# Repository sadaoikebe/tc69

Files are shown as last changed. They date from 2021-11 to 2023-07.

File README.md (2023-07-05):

# TC69 静電容量親指シフト 65% キーボード

## 特徴

オープンソースの親指シフトキーボードです。

* 静電容量式
* QMK対応
* JLCPCBで作成したPCB
* 3Dプリントしたケース

## キーボード配列

* ANSI配列ベース
* 矢印キーあり
* 対応する親指シフトファームウェア [tc69 firmware](https://github.com/sadaoikebe/qmk_firmware/tree/capacitive)
* 親指シフト対応、親指キーB下割れ
* 親指キーに3u/2.75uのキーキャップを使用

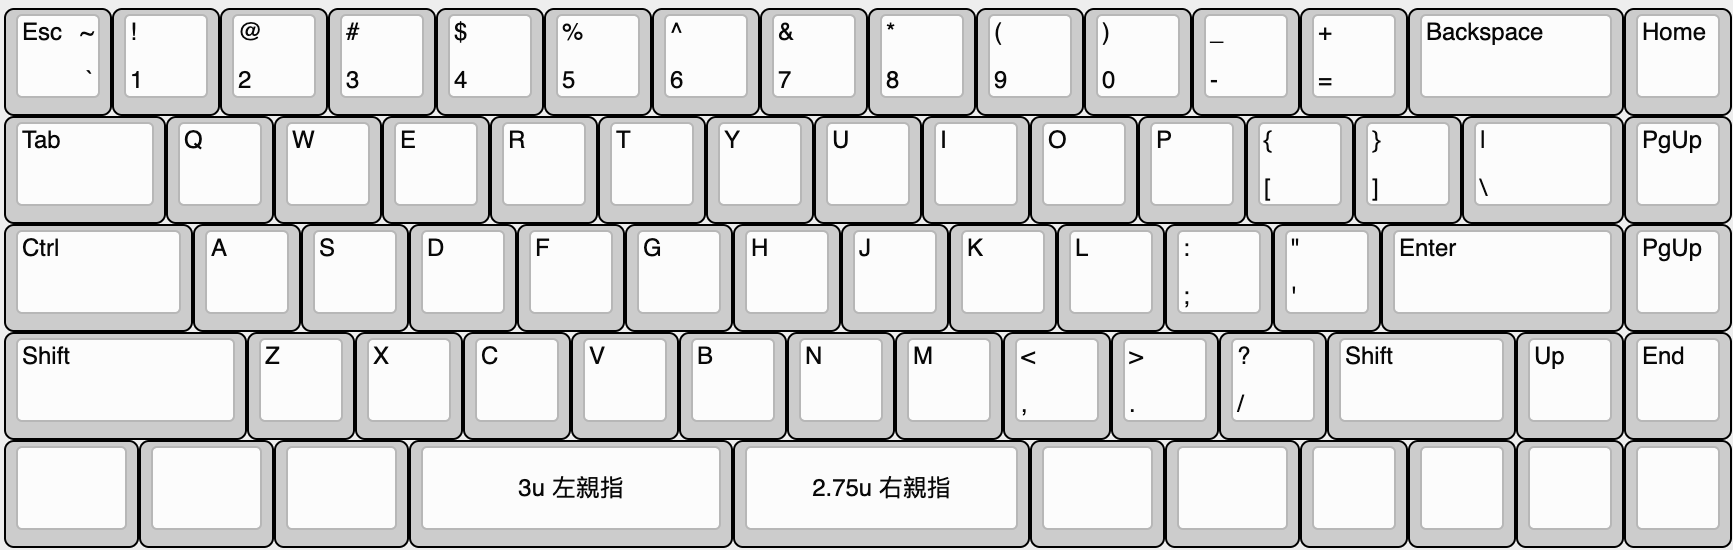
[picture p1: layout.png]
LAYOUT

<!--
["Esc\n\n~\n`","!\n1","@\n2","#\n3","$\n4","%\n5","^\n6","&\n7","*\n8","(\n9",")\n0","_\n-","+\n=",{w:2},"Backspace","Home"],
[{w:1.5},"Tab","Q","W","E","R","T","Y","U","I","O","P","{\n[","}\n]",{w:1.5},"|\n\\","PgUp"],
[{w:1.75},"Ctrl","A","S","D","F","G","H","J","K","L",":\n;","\"\n'",{w:2.25},"Enter","PgUp"],
[{w:2.25},"Shift","Z","X","C","V","B","N","M","<\n,",">\n.","?\n/",{w:1.75},"Shift","Up","End"],
[{a:7,w:1.25},"",{w:1.25},"",{w:1.25},"",{w:3},"3u 左親指",{w:2.75},"2.75u 右親指",{w:1.25},"",{w:1.25},"","","","",""],
-->

静電容量キーボードなので配列は固定で変えられません

# BOM

Item |ソース | 数量 |  備考
:--- | :--- | :--- | :---
TC69 PCBA | [JLCPCB PCBA](pcb/) | 1 |
オペアンプ AD8601ARTZ | AliEx/淘宝等 | 1 |
ロジック 74AHC1G04 | AliEx/淘宝等 | 1 |
ケース | [3D Printed](case/) | 1 | 
定位板 | [Laser Cut Brass](plate/) | 1 | t=1.5mm アクリルでも良いが割れやすい
ヒートセット M3x6mmx4.6mm | [AliEx/淘宝等](https://www.aliexpress.com/item/1005002288716120.html) | 8 | 長さは6mmでなくても良い
M3 円頭六角ボルト 6mm | | 8 |  
M2 低頭精密小ねじ M2*8mm FX-0280EB | [Wilco](https://wilco.jp/products/F/FX-EB.html#page3) | 12 |
クッション 2mm厚 x 60mm x 4mm | | 16 | Poron/EVAフォーム等
Seeed Xiao RP2040 | [Seeed Studio](https://www.seeedstudio.com/XIAO-RP2040-v1-0-p-5026.html) | 1 | 
NiZ プランジャーキット | [NiZ](https://www.nizkeyboard.com/products/2019-new-niz-ec-switch) | 1セット |
コニカルスプリング | [淘宝](https://item.taobao.com/item.htm?spm=a1z0d.6639537/tb.1997196601.4.194d74840XCdqh&id=616137021034) | 69 |
シリコンドーム | [NiZ](https://www.nizkeyboard.com/products/ec-silicone-domes-35g-45g-55g) | 1セット |
2u スタビライザー | AliEx/淘宝/自キ専門店等 | 5 | Plate Mount
3u スタビライザー | AliEx/淘宝/自キ専門店等 | 1 | Plate Mount
キーキャップ | AliEx/淘宝/自キ専門店等 | 1セット | 3u/2.75uの親指キーが必要

## 組み立て工程

1. 定位板はあらかじめM2タップを切る
2. PCBにXiao RP2040, オペアンプ, ロジックIC を取り付け
3. コニカルスプリングを並べてラバードームを乗せる
4. 定位板にハウジングを取り付け、プランジャーを通す
5. 定位板とPCBをM2*8ボルトで緊結する
6. PCBにクッションを貼る
7. ファームウェア書き込み
8. ケースに入れて完成

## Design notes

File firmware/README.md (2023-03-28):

# TC69 Firmware

Use QMK: [tc69 firmware](https://github.com/sadaoikebe/qmk_firmware/tree/capacitive)

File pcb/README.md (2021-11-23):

https://www.seeedstudio.com/blog/2020/04/23/use-seeeduino-xiao-in-kicad-pcb-design-like-a-components/

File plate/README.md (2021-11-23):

https://www.tinkercad.com/things/e4goL4K2fU2-tc69-plate

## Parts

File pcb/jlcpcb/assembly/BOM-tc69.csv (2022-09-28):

Comment | Designator | Footprint | LCSC
100k | R10,R11,R12,R13,R14,R15,R16,R17,R18,R19,R4,R5,R6,R7,R8,R9 | R_0805_2012Metric_Pad1.20x1.40mm_HandSolder | C149504
330p | C2 | C_0603_1608Metric_Pad1.08x0.95mm_HandSolder | C1664
100 | R3 | R_0805_2012Metric_Pad1.20x1.40mm_HandSolder | C17408
1k | R1 | R_0805_2012Metric_Pad1.20x1.40mm_HandSolder | C17513
43k | R2 | R_0805_2012Metric_Pad1.20x1.40mm_HandSolder | C17695
4051 | U4,U5 | SOIC-16_3.9x9.9mm_P1.27mm | C21379
100n | C1,C4,C5,C6 | C_0805_2012Metric_Pad1.18x1.45mm_HandSolder | C28233
74AHC1G04 | U2 | SOT-23-5_HandSoldering | C7465
AD8601ARTZ | U3 | SOT-23-5_HandSoldering | C89851
SeeeduinoXIAO | U1 | Seeeduino XIAO-MOUDLE14P-2.54-21X17.8MM
Y | SW32 | ecs_pad
LSHFT | SW4 | ecs_pad
0 | SW51 | ecs_pad
5 | SW26 | ecs_pad
TAB | SW2 | ecs_pad
6 | SW31 | ecs_pad
9 | SW46 | ecs_pad
2 | SW11 | ecs_pad
7 | SW36 | ecs_pad
ESC | SW1 | ecs_pad
CAPS | SW3 | ecs_pad
LCTRL | SW5 | ecs_pad
1 | SW6 | ecs_pad
Q | SW7 | ecs_pad
LWIN | SW10 | ecs_pad
W | SW12 | ecs_pad
S | SW13 | ecs_pad
Z | SW14 | ecs_pad
3 | SW16 | ecs_pad
E | SW17 | ecs_pad
D | SW18 | ecs_pad
X | SW19 | ecs_pad
LALT | SW20 | ecs_pad
4 | SW21 | ecs_pad
R | SW22 | ecs_pad
F | SW23 | ecs_pad
C | SW24 | ecs_pad
T | SW27 | ecs_pad
G | SW28 | ecs_pad
V | SW29 | ecs_pad
LSPC | SW30 | ecs_pad
H | SW33 | ecs_pad
B | SW34 | ecs_pad
U | SW37 | ecs_pad
J | SW38 | ecs_pad
N | SW39 | ecs_pad
8 | SW41 | ecs_pad
I | SW42 | ecs_pad
K | SW43 | ecs_pad
M | SW44 | ecs_pad
RSPC | SW45 | ecs_pad
O | SW47 | ecs_pad
L | SW48 | ecs_pad
COMMA | SW49 | ecs_pad
P | SW52 | ecs_pad
SCLN | SW53 | ecs_pad
DOT | SW54 | ecs_pad
RALT | SW55 | ecs_pad
MINUS | SW56 | ecs_pad
LBRC | SW57 | ecs_pad
QUOTE | SW58 | ecs_pad
SLSH | SW59 | ecs_pad
RWIN | SW60 | ecs_pad
EQUAL | SW61 | ecs_pad
RBRC | SW62 | ecs_pad
APP | SW65 | ecs_pad
BS | SW66 | ecs_pad
ENTER | SW68 | ecs_pad
RSHFT | SW69 | ecs_pad
LEFT | SW70 | ecs_pad
BSLSH | SW72 | ecs_pad
UP | SW74 | ecs_pad
DOWN | SW75 | ecs_pad
HOME | SW76 | ecs_pad
PGUP | SW77 | ecs_pad
PGDN | SW78 | ecs_pad
END | SW79 | ecs_pad
RIGHT | SW80 | ecs_pad
A | SW8 | ecs_pad

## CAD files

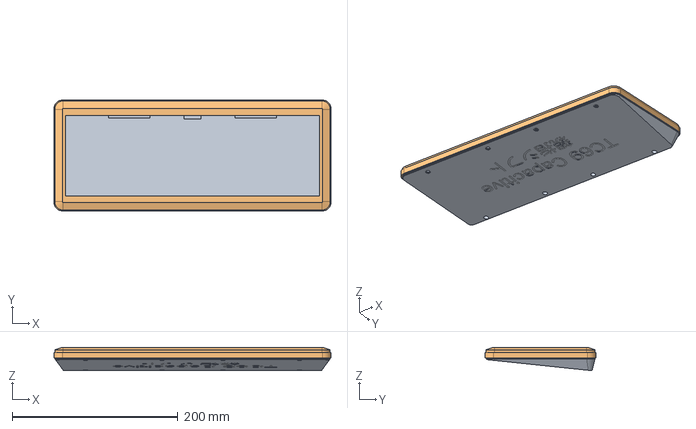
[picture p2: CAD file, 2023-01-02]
case/tc69-case.FCStd
334.0 x 133.5 x 28.2 mm
Base
Lid

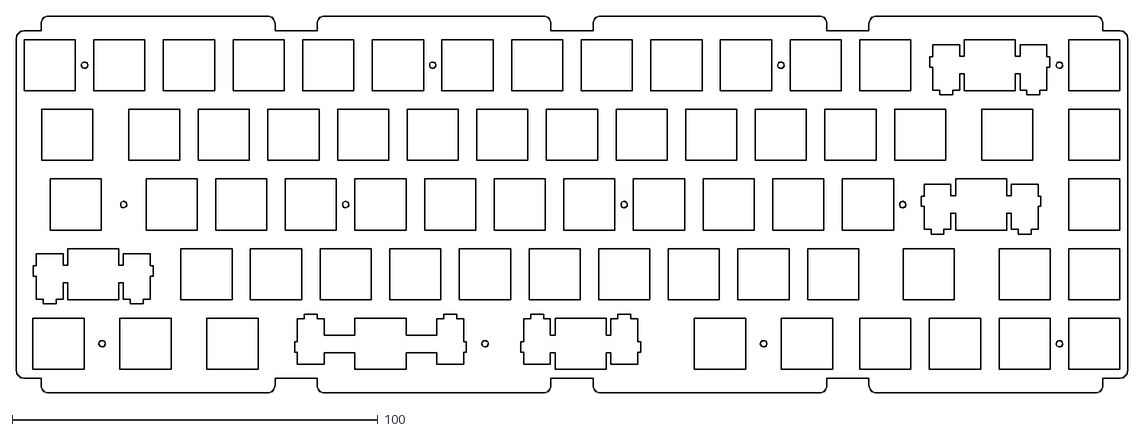
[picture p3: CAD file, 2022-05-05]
plate/tc69_plate.dxf
304.0 x 103.0

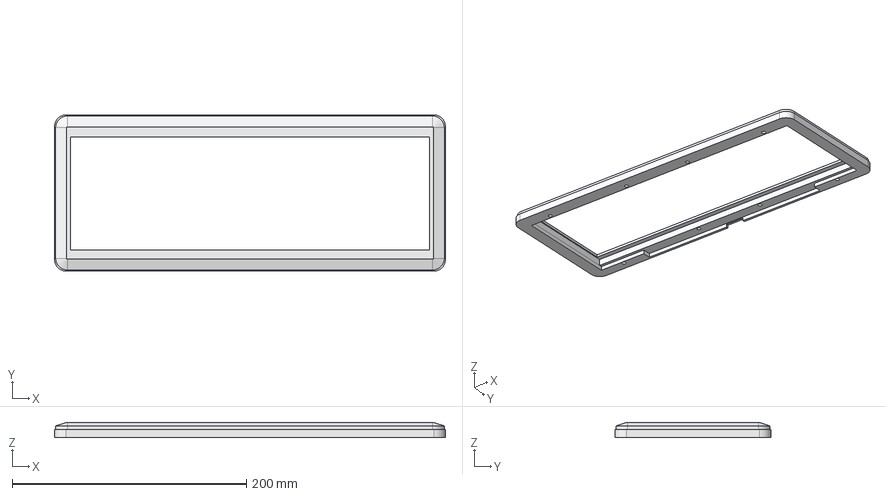
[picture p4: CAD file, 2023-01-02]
case/tc69-case-Lid.step
334.0 x 133.5 x 13.0 mm

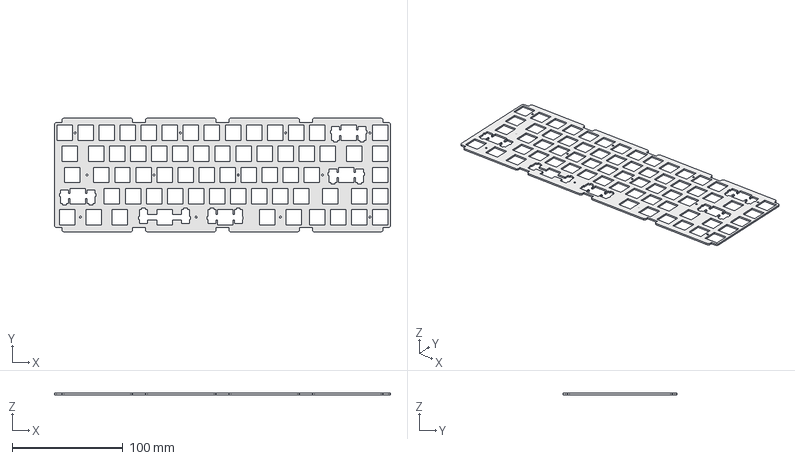
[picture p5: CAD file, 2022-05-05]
plate/plate.FCStd
304.0 x 103.0 x 1.50 mm

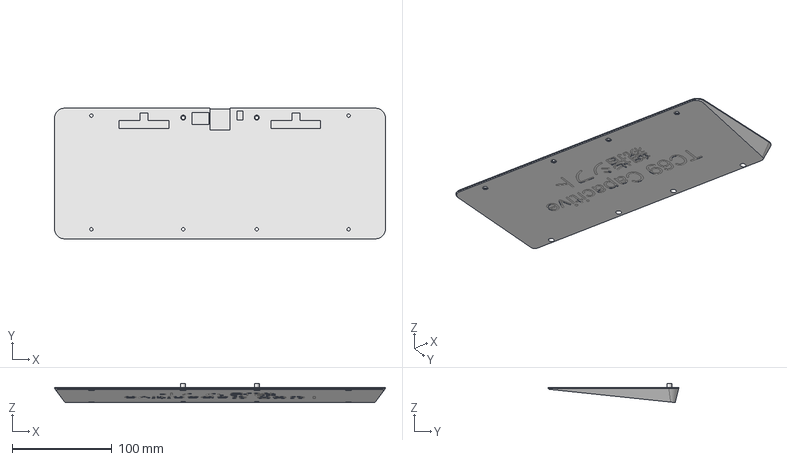
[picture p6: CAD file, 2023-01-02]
case/tc69-case-Base.step
332.0 x 131.0 x 19.2 mm

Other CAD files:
pcb/CapacitivePad.FCStd
case/tc69-case-Base.3mf
case/tc69-case-Lid.3mf

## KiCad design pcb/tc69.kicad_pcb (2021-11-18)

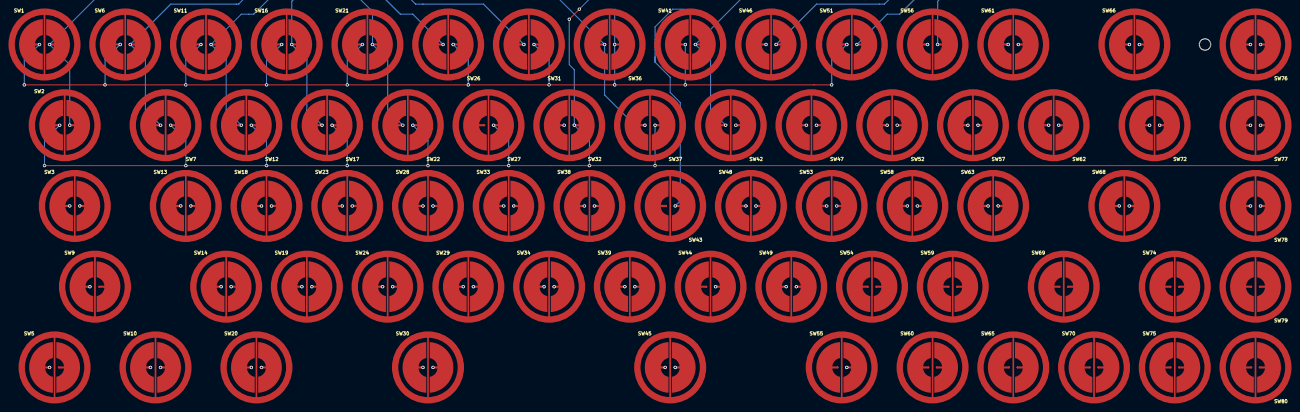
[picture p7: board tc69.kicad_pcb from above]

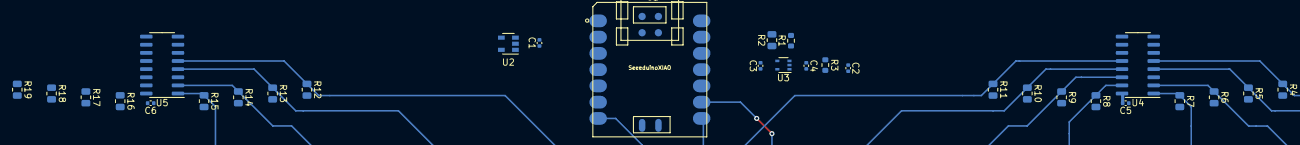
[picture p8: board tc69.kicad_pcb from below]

Board: 2 copper layers, 99 parts (30 on the bottom side), 32 nets.

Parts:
C1, C4, C5, C6: 100n; C_0402_1005Metric
C2: 330p; C_0402_1005Metric
C3: 10p; C_0402_1005Metric
R1: 1k; R_0603_1608Metric
R2: 43k; R_0805_2012Metric
R3: 100; R_0603_1608Metric
R4, R5, R6, R7, R8, R9, R10, R11, R12, R13, R14, R15, R16, R17, R18, R19: 100k; R_0805_2012Metric
SW1: ESC; ecs_pad
SW2: TAB; ecs_pad
SW3: CAPS; ecs_pad
SW5: LCTRL; ecs_pad
SW6: 1; ecs_pad
SW7: Q; ecs_pad
SW9: LSHFT; ecs_pad
SW10: LWIN; ecs_pad
SW11: 2; ecs_pad
SW12: W; ecs_pad
SW13: A; ecs_pad
SW14: Z; ecs_pad
SW16: 3; ecs_pad
SW17: E; ecs_pad
SW18: S; ecs_pad
SW19: X; ecs_pad
SW20: LALT; ecs_pad
SW21: 4; ecs_pad
SW22: R; ecs_pad
SW23: D; ecs_pad
SW24: C; ecs_pad
SW26: 5; ecs_pad
SW27: T; ecs_pad
SW28: F; ecs_pad
SW29: V; ecs_pad
SW30: LSPC; ecs_pad
SW31: 6; ecs_pad
SW32: Y; ecs_pad
SW33: G; ecs_pad
SW34: B; ecs_pad
SW36: 7; ecs_pad
SW37: U; ecs_pad
SW38: H; ecs_pad
SW39: N; ecs_pad
SW41: 8; ecs_pad
SW42: I; ecs_pad
SW43: J; ecs_pad
SW44: M; ecs_pad
SW45: RSPC; ecs_pad
SW46: 9; ecs_pad
SW47: O; ecs_pad
SW48: K; ecs_pad
SW49: COMMA; ecs_pad
SW51: 0; ecs_pad
SW52: P; ecs_pad
SW53: L; ecs_pad
SW54: DOT; ecs_pad
SW55: RALT; ecs_pad
SW56: MINUS; ecs_pad
SW57: LBRC; ecs_pad
SW58: SCLN; ecs_pad
SW59: SLSH; ecs_pad
SW60: RWIN; ecs_pad
SW61: EQUAL; ecs_pad
SW62: RBRC; ecs_pad
SW63: QUOTE; ecs_pad
SW65: APP; ecs_pad
SW66: BS; ecs_pad
SW68: ENTER; ecs_pad
SW69: RSHFT; ecs_pad
SW70: LEFT; ecs_pad
SW72: BSLSH; ecs_pad
SW74: UP; ecs_pad
SW75: DOWN; ecs_pad
SW76: HOME; ecs_pad
SW77: PGUP; ecs_pad
SW78: PGDN; ecs_pad
SW79: END; ecs_pad
SW80: RIGHT; ecs_pad
U1: SeeeduinoXIAO; Seeeduino XIAO-MOUDLE14P-2.54-21X17.8MM
U2: 74AHC1G04; SOT-23-5
U3: TLV9051; SOT-353_SC-70-5
U4, U5: 4051; SOIC-16_3.9x9.9mm_P1.27mm

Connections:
+5V: C1.2, C4.2, C5.2, C6.2, U1.14, U2.5, U3.5, U4.16, U5.16
ADC: C3.1, R2.1, U1.11, U3.4
GND: C1.1, C2.2, C4.1, C5.1, C6.1, R1.2, R4.2, R5.2, R6.2, R7.2, R8.2, R9.2, R10.2, R11.2, R12.2, R13.2, R14.2, R15.2, R16.2, R17.2, R18.2, R19.2, SW1.3, SW2.3, SW3.3, SW5.3, SW6.3, SW7.3, SW9.3, SW10.3, SW11.3, SW12.3, SW13.3, SW14.3, SW16.3, SW17.3, SW18.3, SW19.3, SW20.3, SW21.3, SW22.3, SW23.3, SW24.3, SW26.3, SW27.3, SW28.3, SW29.3, SW30.3, SW31.3, SW32.3, SW33.3, SW34.3, SW36.3, SW37.3, SW38.3, SW39.3, SW41.3, SW42.3, SW43.3, SW44.3, SW45.3, SW46.3, SW47.3, SW48.3, SW49.3, SW51.3, SW52.3, SW53.3, SW54.3, SW55.3, SW56.3, SW57.3, SW58.3, SW59.3, SW60.3, SW61.3, SW62.3, SW63.3, SW65.3, SW66.3, SW68.3, SW69.3, SW70.3, SW72.3, SW74.3, SW75.3, SW76.3, SW77.3, SW78.3, SW79.3, SW80.3, U1.13, U2.3, U3.2, U4.7, U4.8, U5.7, U5.8
IS0: U2.4, U5.6
unnamed: C3.2, R1.1, R2.2, U3.3
unnamed: R3.1, U3.1
S0: U1.1, U2.2, U4.6
S1: U1.2, U4.11, U5.11
S2: U1.3, U4.10, U5.10
S3: U1.4, U4.9, U5.9
SENSE: C2.1, R3.2, U1.10, U4.3, U5.3
col1: R4.1, SW1.2, SW2.2, SW3.2, SW5.2, U4.5
col2: R5.1, SW6.2, SW7.2, SW9.2, SW10.2, U4.4
col3: R6.1, SW11.2, SW12.2, SW13.2, SW14.2, U4.2
col4: R7.1, SW16.2, SW17.2, SW18.2, SW19.2, SW20.2, U4.1
col5: R8.1, SW21.2, SW22.2, SW23.2, SW24.2, U4.15
col6: R9.1, SW26.2, SW27.2, SW28.2, SW29.2, SW30.2, U4.14
col7: R10.1, SW31.2, SW32.2, SW33.2, SW34.2, U4.13
col8: R11.1, SW36.2, SW37.2, SW38.2, SW39.2, U4.12
col9: R12.1, SW41.2, SW42.2, SW43.2, SW44.2, SW45.2, U5.5
col10: R13.1, SW46.2, SW47.2, SW48.2, SW49.2, U5.4
col11: R14.1, SW51.2, SW52.2, SW53.2, SW54.2, SW55.2, U5.2
col12: R15.1, SW56.2, SW57.2, SW58.2, SW59.2, SW60.2, U5.1
col13: R16.1, SW61.2, SW62.2, SW63.2, SW65.2, U5.15
col14: R17.1, SW66.2, SW68.2, SW69.2, SW70.2, U5.14
col15: R18.1, SW72.2, SW74.2, SW75.2, U5.13
col16: R19.1, SW76.2, SW77.2, SW78.2, SW79.2, SW80.2, U5.12
row1: SW1.1, SW6.1, SW11.1, SW16.1, SW21.1, SW26.1, SW31.1, SW36.1, SW41.1, SW46.1, SW51.1, SW56.1, SW61.1, SW66.1, SW76.1, U1.8
row2: SW2.1, SW7.1, SW12.1, SW17.1, SW22.1, SW27.1, SW32.1, SW37.1, SW42.1, SW47.1, SW52.1, SW57.1, SW62.1, SW72.1, SW77.1, U1.9
row3: SW3.1, SW13.1, SW18.1, SW23.1, SW28.1, SW33.1, SW38.1, SW43.1, SW48.1, SW53.1, SW58.1, SW63.1, SW68.1, SW78.1, U1.7
row4: SW9.1, SW14.1, SW19.1, SW24.1, SW29.1, SW34.1, SW39.1, SW44.1, SW49.1, SW54.1, SW59.1, SW69.1, SW74.1, SW79.1, U1.6
row5: SW5.1, SW10.1, SW20.1, SW30.1, SW45.1, SW55.1, SW60.1, SW65.1, SW70.1, SW75.1, SW80.1, U1.5

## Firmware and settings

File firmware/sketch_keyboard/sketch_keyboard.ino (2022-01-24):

#include "sketch_keyboard.h"
#include "keymap.h"

void setup() {
  //Serial.begin(9600);

  // multiplexer
  pinMode(COLS[0], OUTPUT);
  pinMode(COLS[1], OUTPUT);
  pinMode(COLS[2], OUTPUT);
  pinMode(COLS[3], OUTPUT);

  // purge pin
  pinMode(PURGE, INPUT);

  // sense pin
  pinMode(SENSE, INPUT);

  // trigger
  pinMode(ROWS[0], OUTPUT);
  pinMode(ROWS[1], OUTPUT);
  pinMode(ROWS[2], OUTPUT);
  pinMode(ROWS[3], OUTPUT);
  pinMode(ROWS[4], OUTPUT);
  
  calibrate_adc();
}

bool fn_pressed = false;

void loop() {
  static matrix_row_t matrix_prev[MATRIX_ROWS];
  matrix_row_t        matrix_row    = 0;
  matrix_row_t        matrix_change = 0;

  uint8_t matrix_changed = matrix_scan();

  for (uint8_t r = 0; r < MATRIX_ROWS; r++) {
    matrix_row    = matrix_get_row(r);
    matrix_change = matrix_row ^ matrix_prev[r];
    if (matrix_change) {
      matrix_row_t col_mask = 1;
      for (uint8_t c = 0; c < MATRIX_COLS; c++, col_mask <<= 1) {
        if (matrix_change & col_mask) {
          uint16_t keycode = keymap_base[r][c];
          bool pressed = matrix_row & col_mask;

          if(keycode == 0) {
            fn_pressed = pressed;
          }
          if(fn_pressed && keymap_fn[r][c] > 1) {
            keycode = keymap_fn[r][c];
          }
          else if(is_nicola_layer(keycode, pressed) && keymap_nicola[r][c] > 1) {
            keycode = keymap_nicola[r][c];
          }
          
          //Serial.print(pressed ? "P" : "R");
          //Serial.print(' ');
          //Serial.print(keycode);
          //Serial.print(' ');
          //Serial.print(r);
          //Serial.print(' ');
          //Serial.println(c);
          
          if(keycode == KEY_NICOLA_ON) {
            if(pressed) {
              nicola_on();
            }
            matrix_prev[r] ^= col_mask;
            continue;
          } else if(keycode == KEY_NICOLA_OFF) {
            if(pressed) {
              nicola_off();
            }
            matrix_prev[r] ^= col_mask;
            continue;
          }
          if(nicola_state()) {
            if(!process_nicola(keycode, pressed)) {
              matrix_prev[r] ^= col_mask;
              continue;
            }
          }
          if(keycode > 1 && keycode <= 0xff) {
            if(pressed) {
              Keyboard.press(keycode);
            } else {
              Keyboard.release(keycode);
            }
          }
          matrix_prev[r] ^= col_mask;
        }
      }
    }
  }
}

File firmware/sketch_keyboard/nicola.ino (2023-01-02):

/* Copyright 2018-2019 eswai <@eswai>
 *
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
 * You should have received a copy of the GNU General Public License
 * along with this program.  If not, see <http://www.gnu.org/licenses/>.
 */
/*
 * introduced NICOLA state machine
 * (C) 2020 Sadao Ikebe @bonyarou
 */

#include "keymap.h"

static bool is_nicola = false; // 親指シフトがオンかオフか
static uint8_t n_modifier = 0; // 押しているmodifierキーの数

#define TIMEOUT_THRESHOLD (150)
#define OVERLAP_THRESHOLD (20)

typedef enum {
  NICOLA_STATE_S1_INIT,
  NICOLA_STATE_S2_M,
  NICOLA_STATE_S3_O,
  NICOLA_STATE_S4_MO,
  NICOLA_STATE_S5_OM
} nicola_state_t;

static nicola_state_t nicola_int_state = NICOLA_STATE_S1_INIT;
static int nicola_m_key;
static int nicola_o_key;
static uint16_t nicola_m_time;
static uint16_t nicola_o_time;

#define IF_TIMEOUT(x) if(x)

// 親指シフトをオンオフ
void nicola_on(void) {
  is_nicola = true;
  nicola_clear();

  Keyboard.press(KEY_CONVERT);
  delayMicroseconds(5);
  Keyboard.release(KEY_CONVERT);
  delayMicroseconds(5);
  Keyboard.press(KEY_LANG1);
  delayMicroseconds(5);
  Keyboard.release(KEY_LANG1);
}

void nicola_off(void) {
  is_nicola = false;
  nicola_clear();

  Keyboard.press(KEY_NOCONVERT);
  delayMicroseconds(5);
  Keyboard.release(KEY_NOCONVERT);
  delayMicroseconds(5);
  Keyboard.press(KEY_LANG2);
  delayMicroseconds(5);
  Keyboard.release(KEY_LANG2);
}

// 親指シフトの状態
bool nicola_state(void) {
  return is_nicola;
}

// バッファをクリアする
void nicola_clear(void) {
  nicola_int_state = NICOLA_STATE_S1_INIT;
}

// 入力モードか編集モードかを確認する
bool is_nicola_layer(uint16_t keycode, bool pressed) {
  if (!is_nicola) return false;

  // modifierが押されたらレイヤーをオフ
  switch (keycode) {
    case KEY_LEFT_CTRL:
    case KEY_LEFT_SHIFT:
    case KEY_LEFT_ALT:
    case KEY_LEFT_GUI:
    case KEY_RIGHT_CTRL:
    case KEY_RIGHT_SHIFT:
    case KEY_RIGHT_ALT:
    case KEY_RIGHT_GUI:
      if (pressed) {
        if(n_modifier == 0) {
          return false;
        }
        n_modifier++;
      } else {
        n_modifier--;
        if (n_modifier == 0) {
          return true;
        }
      }
      break;
  }

  return true;
}

void nicola_m_type(void) {
    switch(nicola_m_key) {
        case NG_1   : Keyboard.write((const uint8_t*)"1", 1); break;
        case NG_2   : Keyboard.write((const uint8_t*)"2", 1); break;
        case NG_3   : Keyboard.write((const uint8_t*)"3", 1); break;
        case NG_4   : Keyboard.write((const uint8_t*)"4", 1); break;
        case NG_5   : Keyboard.write((const uint8_t*)"5", 1); break;
        case NG_6   : Keyboard.write((const uint8_t*)"6", 1); break;
        case NG_7   : Keyboard.write((const uint8_t*)"7", 1); break;
        case NG_8   : Keyboard.write((const uint8_t*)"8", 1); break;
        case NG_9   : Keyboard.write((const uint8_t*)"9", 1); break;
        case NG_0   : Keyboard.write((const uint8_t*)"0", 1); break;
        case NG_MINS: Keyboard.write((const uint8_t*)"-", 1); break;
        case NG_EQL : Keyboard.write((const uint8_t*)"=", 1); break;

        case NG_Q   : Keyboard.write((const uint8_t*)"." ,1); break;
        case NG_W   : Keyboard.write((const uint8_t*)"ka",2); break;
        case NG_E   : Keyboard.write((const uint8_t*)"ta",2); break;
        case NG_R   : Keyboard.write((const uint8_t*)"ko",2); break;
        case NG_T   : Keyboard.write((const uint8_t*)"sa",2); break;
        case NG_Y   : Keyboard.write((const uint8_t*)"ra",2); break;
        case NG_U   : Keyboard.write((const uint8_t*)"ti",2); break;
        case NG_I   : Keyboard.write((const uint8_t*)"ku",2); break;
        case NG_O   : Keyboard.write((const uint8_t*)"tu",2); break;
        case NG_P   : Keyboard.write((const uint8_t*)"," ,1); break;
        case NG_LBRC: Keyboard.write((const uint8_t*)"," ,1); break;
        case NG_RBRC: Keyboard.write((const uint8_t*)";" ,1); break;
        case NG_BSLS: Keyboard.write((const uint8_t*)"\\",1); break;

        case NG_A   : Keyboard.write((const uint8_t*)"u" ,1); break;
        case NG_S   : Keyboard.write((const uint8_t*)"si",2); break;
        case NG_D   : Keyboard.write((const uint8_t*)"te",2); break;
        case NG_F   : Keyboard.write((const uint8_t*)"ke",2); break;
        case NG_G   : Keyboard.write((const uint8_t*)"se",2); break;
        case NG_H   : Keyboard.write((const uint8_t*)"ha",2); break;
        case NG_J   : Keyboard.write((const uint8_t*)"to",2); break;
        case NG_K   : Keyboard.write((const uint8_t*)"ki",2); break;
        case NG_L   : Keyboard.write((const uint8_t*)"i" ,1); break;
        case NG_SCLN: Keyboard.write((const uint8_t*)"nn",22); break;
        case NG_QUOT: Keyboard.write((const uint8_t*)"\xb2",1); break;

        case NG_Z   : Keyboard.write((const uint8_t*)"." ,1); break;
        case NG_X   : Keyboard.write((const uint8_t*)"hi",2); break;
        case NG_C   : Keyboard.write((const uint8_t*)"su",2); break;
        case NG_V   : Keyboard.write((const uint8_t*)"hu",2); break;
        case NG_B   : Keyboard.write((const uint8_t*)"he",2); break;
        case NG_N   : Keyboard.write((const uint8_t*)"me",2); break;
        case NG_M   : Keyboard.write((const uint8_t*)"so",2); break;
        case NG_COMM: Keyboard.write((const uint8_t*)"ne",2); break;
        case NG_DOT : Keyboard.write((const uint8_t*)"ho",2); break;
        case NG_SLSH: Keyboard.write((const uint8_t*)"/" ,1); break;
    }
}

void nicola_o_type(void) {
    if(nicola_o_key != 0) {
        Keyboard.write((const uint8_t*)" ", 1);
    }
}
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

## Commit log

2021-11-17 partly routed
    [tc69.kicad_pcb]
2021-11-18 wire a bit
    [tc69.kicad_pcb, tc69.sch]
2021-11-18 switch wired
    [tc69.sch]
2021-11-18 adjust wire
2021-11-19 wire complete
    [tc69.sch]
2021-11-21 handsolder pad
    [tc69.sch]
2021-11-22 gnd plane
    [tc69.sch]
2021-11-22 trace adjust
    [tc69.sch]
2021-11-23 added hole and plate
    [tc69-B_Cu.gbl, tc69-B_Mask.gbs, tc69-B_Paste.gbp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]
2022-01-11 fix power line, made xiao rp2040 compatible
    [tc69.sch]
2022-01-12 debounce to ADC hysteresis
2022-01-24 fix op-amp output
    [tc69.sch]
2022-03-23 add freecad model
    [tc69-case.FCStd, tc69.kicad_sch]
2022-04-08 jlcpcb r2
    [tc69-B_Cu.gbl, tc69-B_Mask.gbs, tc69-B_Paste.gbp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]
2022-04-08 case and plate ongoing
    [BOM-tc69.csv, plate.FCStd, tc69-case-Base.stl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]
2022-04-20 holes for 2u and 3u
    [plate.FCStd]
2022-05-02 pcb re-wired
    [plate.FCStd]
2022-05-02 roundtracks and teardrops
    [plate.FCStd]
2022-05-02 add round case
    [tc69-case-2-Base.stl, tc69-case-2-Lid.stl, tc69-case-2.FCStd]
2022-05-05 plate finished
    [plate.FCStd, tc69_plate.dxf]
2022-05-20 add footprint
    [CapacitivePad.FCStd]
2022-05-20 modify pad dimension
    [CapacitivePad.FCStd]
2022-05-20 add keepout on F_Cu
    [tc69.kicad_sch]
2022-05-20 change silkscreen; jlcpcb r3.1 ...
    [CapacitivePad.FCStd]
2022-05-21 changed pad shape
    [CapacitivePad.FCStd]
2022-05-24 increase angle
    [tc69-case-2-Base.stl, tc69-case-2-Lid.stl, tc69-case-2.FCStd]
2022-09-28 revert to the rp2040 version
    [BOM-tc69.csv, tc69.kicad_sch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]
2022-09-28 rotate 4051
    [POS-tc69.csv]
2023-01-02 case rev3 with sensitivity tweak
    [tc69-case-2-Base.stl, tc69-case-2-Lid.stl, tc69-case-2.FCStd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]
2023-03-28 add tester
    [tc69-CuBottom.gbr, tc69-CuTop.gbr, tc69-EdgeCuts.gbr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]

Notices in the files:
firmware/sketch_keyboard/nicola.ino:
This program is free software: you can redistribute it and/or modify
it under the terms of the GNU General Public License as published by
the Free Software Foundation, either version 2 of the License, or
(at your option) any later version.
